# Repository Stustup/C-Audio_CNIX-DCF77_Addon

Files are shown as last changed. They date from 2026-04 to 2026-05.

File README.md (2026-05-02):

# DCF77 Addon Board for the C-Audio Nixie Clock (CNIX)
(This project was sponsored by PCBWay)

This board adds automatic time setting via a DCF77 radio to CNIX. Also temperature and humidity readings are possible with a HTU21 sensor from TE Connectivity which can be read via I2C and viewed via the first submenu on the clock (instead of the manual time setting). The antenna is hold in place with cable ties.

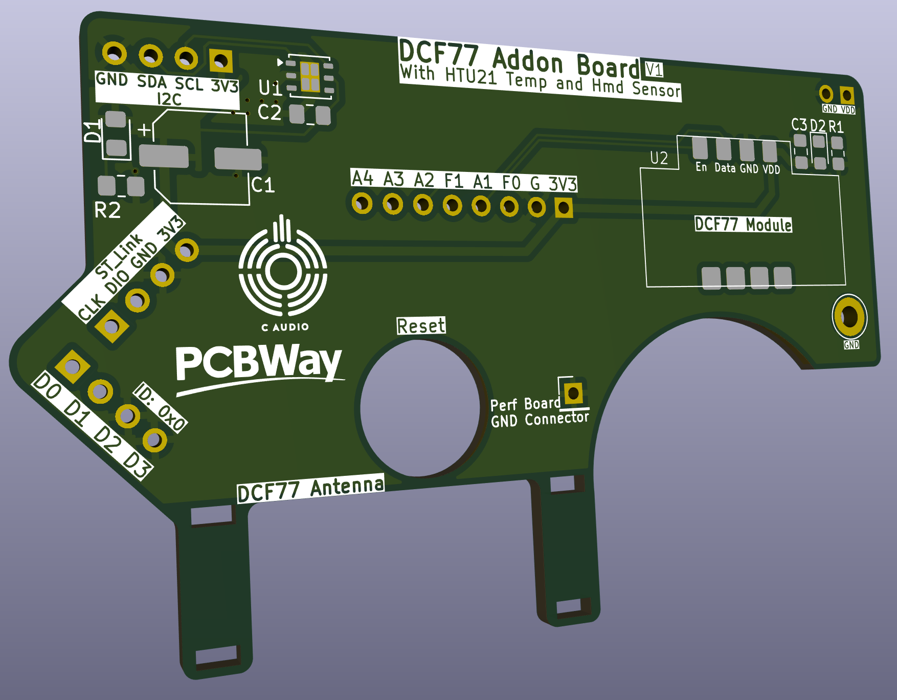
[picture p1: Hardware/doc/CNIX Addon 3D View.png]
3D view of the board without the clock


The breakout pins are still accessable, as well as the I2C breakout, which can be used with a display while debugging.   

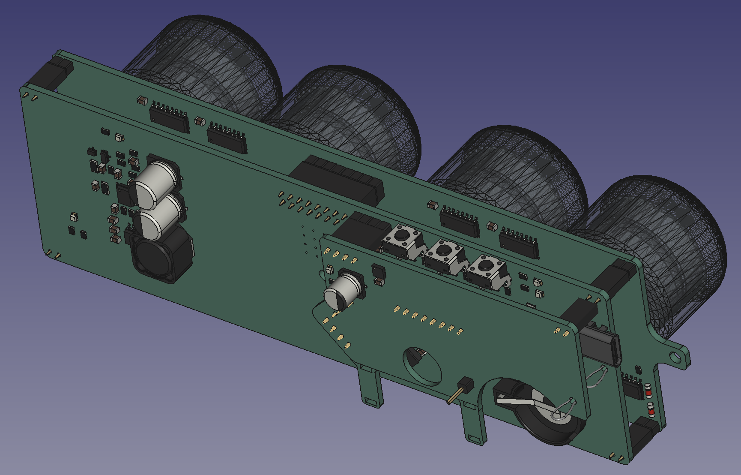
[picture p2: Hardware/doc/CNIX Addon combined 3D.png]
3D view of the all three boards of CNIX
 Real world picture of the board with attached antenna 

The code to communicate with the modules remains on the main control PCB, which you can find [here](https://github.com/Stustup/C-Nixie_CNIX). This board uses the integrated ID system of CNIX via pins D2 and D3 and has the adress 0x0 (first addon board).

The addon board was sponsored by PCBWay. As always, their service was amazing and the facbrication as well as the shipping was fast. Because of the all-in-one customs and shipping price the handling of taxes and other fees was very easy.
I highly recommend their services if you want to build this PCB. [Click here](https://www.pcbway.com/orderonline.aspx) to get to the order form if you want to order this or any other PCBs.

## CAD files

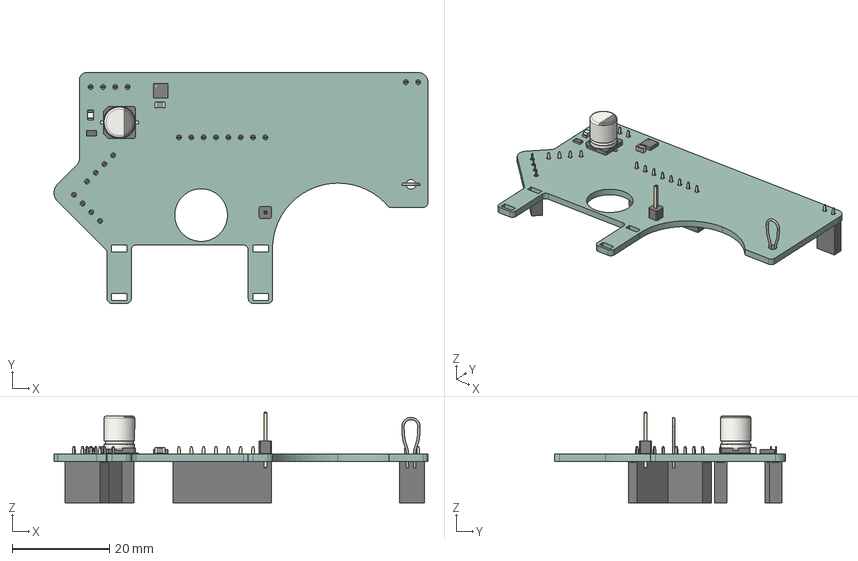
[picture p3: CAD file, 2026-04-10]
Hardware/KiCAD/DCF77-Addon/3D/DCF77-Addon.step
77.0 x 47.5 x 18.7 mm
TestPoint_Loop_D3.80mm_Drill2.0mm
R_0805_2012Metric
CP_Elec_6.3x7.7
PinHeader_1x01_P2.54mm_Vertical
C_0805_2012Metric
LED_0805_2012Metric
DFN-6-1EP_3x3mm_P0.95mm_EP1.7x2.6mm
PinSocket_1x02_P2.54mm_Vertical
PinSocket_1x04_P2.54mm_Vertical x 3
PinSocket_1x08_P2.54mm_Vertical
DCF77-Addon_PCB

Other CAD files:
Hardware/KiCAD/DCF77-Addon/3D/DCF77 Addon.FCStd

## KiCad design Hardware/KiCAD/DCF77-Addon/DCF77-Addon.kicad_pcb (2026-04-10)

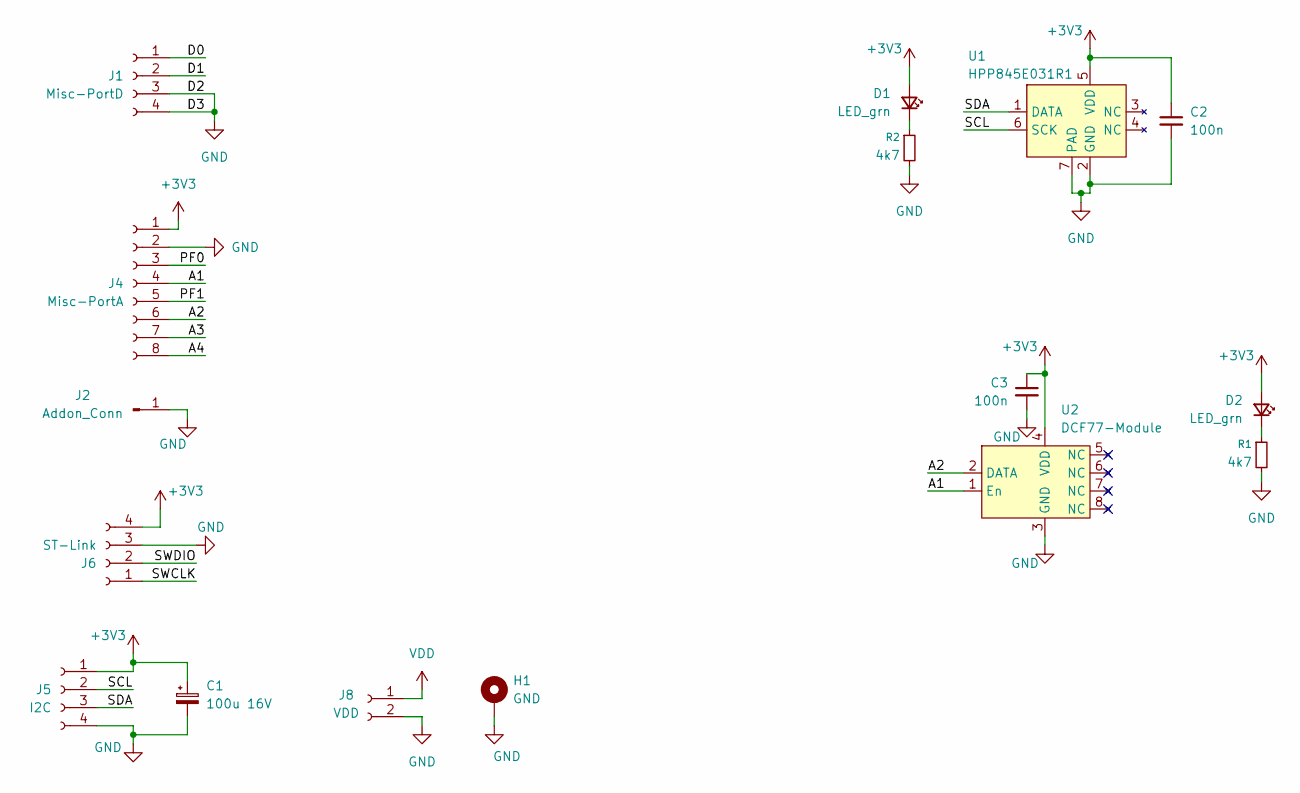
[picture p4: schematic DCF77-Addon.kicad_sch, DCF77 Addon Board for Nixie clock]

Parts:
C1: 100u 16V; CP_Elec_6.3x7.7
C2, C3: 100n; C_0805_2012Metric_Pad1.18x1.45mm_HandSolder
D1, D2: LED_grn; LED_0805_2012Metric_Pad1.15x1.40mm_HandSolder
H1: GND; TestPoint_Loop_D3.80mm_Drill2.0mm
J1: Misc-PortD; PinSocket_1x04_P2.54mm_Vertical
J2: Addon_Conn; PinHeader_1x01_P2.54mm_Vertical
J4: Misc-PortA; PinSocket_1x08_P2.54mm_Vertical
J5: I2C; PinSocket_1x04_P2.54mm_Vertical
J6: ST-Link; PinSocket_1x04_P2.54mm_Vertical
J8: VDD; PinSocket_1x02_P2.54mm_Vertical
R1, R2: 4k7; R_0805_2012Metric_Pad1.20x1.40mm_HandSolder
U1: HPP845E031R1; Maxim_TDFN-6-1EP_3x3mm_P0.95mm_EP1.5x2.3mm; Mouser Nr. 824-HPP845E031R1
U2: DCF77-Module

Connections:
+3V3: C1.1, C2.1, C3.1, D1.2 (A), D2.2 (A), J4.1, J5.1, J6.4, U1.5 (VDD), U2.4 (VDD)
/A1: J4.4, U2.1 (En)
/A2: J4.6, U2.2 (DATA)
/A3: J4.7
/A4: J4.8
/D0: J1.1
/D1: J1.2
/PF0: J4.3
/PF1: J4.5
/SCL: J5.2, U1.6 (SCK)
/SDA: J5.3, U1.1 (DATA)
/SWCLK: J6.1
/SWDIO: J6.2
GND: C1.2, C2.2, C3.2, H1.1, J1.3, J1.4, J2.1, J4.2, J5.4, J6.3, J8.2, R1.2, R2.2, U1.2 (GND), U1.7 (PAD), U2.3 (GND)
unnamed: D1.1 (K), R2.1
unnamed: D2.1 (K), R1.1
VDD: J8.1

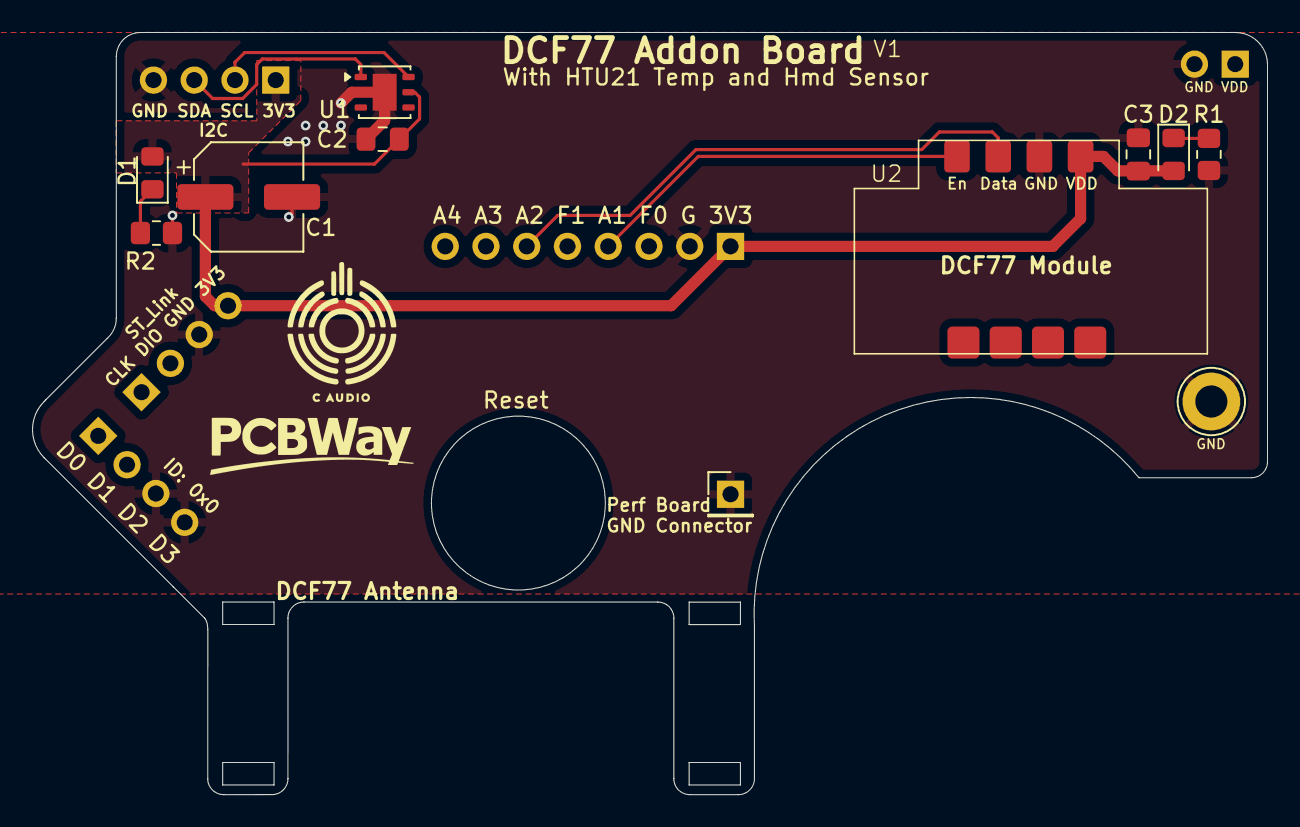
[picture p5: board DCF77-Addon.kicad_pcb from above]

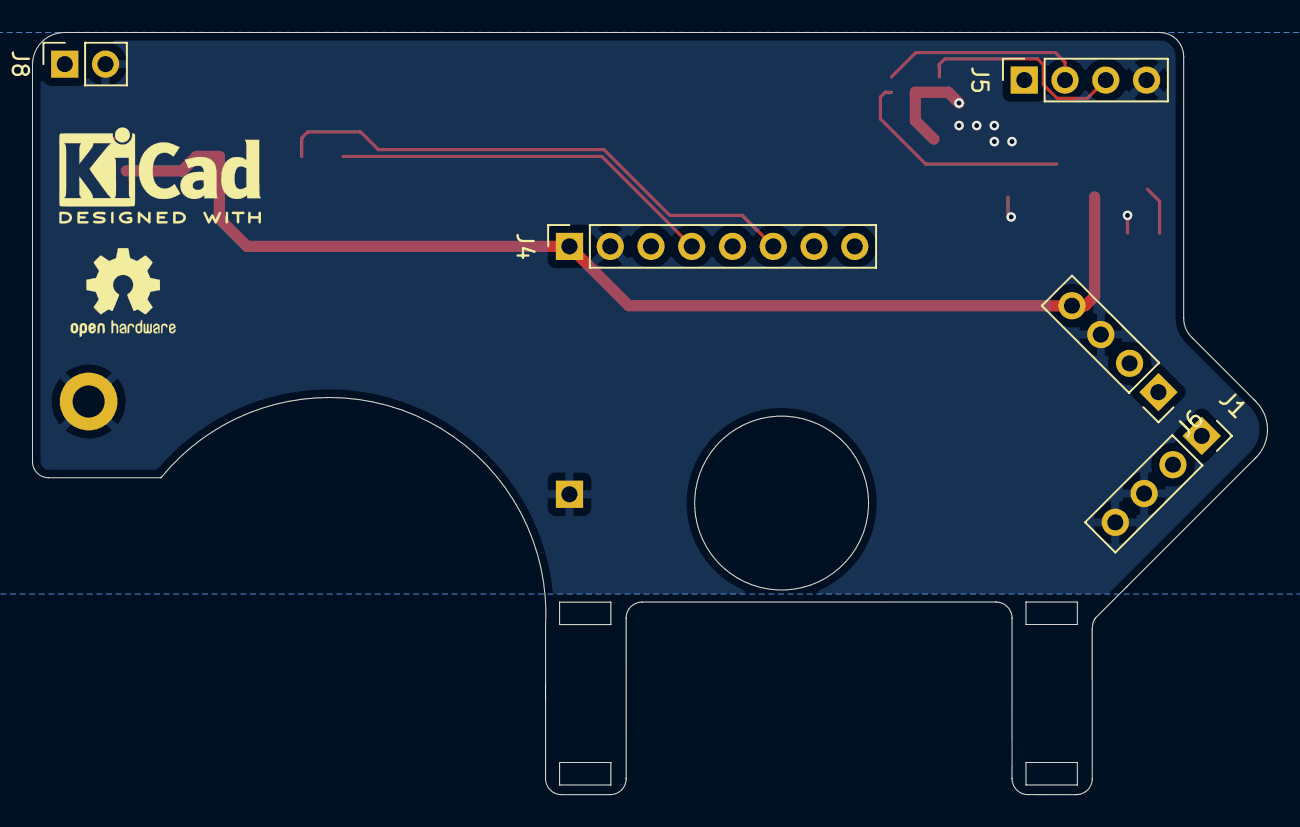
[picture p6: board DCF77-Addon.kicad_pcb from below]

Board: 2 copper layers, 77.0 x 47.5 mm, 16 parts (5 on the bottom side), 8 nets.

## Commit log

2026-04-10 added everything
    [DCF77 Addon.FCStd, DCF77-Addon.kicad_pcb, DCF77-Addon.kicad_sch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]
2026-05-02 Added PCBWay link
    Added a link to the PCBWay order form for easier access.
